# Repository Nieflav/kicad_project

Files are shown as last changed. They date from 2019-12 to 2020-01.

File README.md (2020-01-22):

# Arduino Gas Sensor shield

This PCB was created using KiCad. The schematic has been created from an Arduino Uno shield template. As a consequence, this board will be easily pluggable on top of an Arduino Uno. This board includes a TO-5 package socket for the gas sensor [U4] (supplied by the +3V3 output of the Arduino [pin 4]).

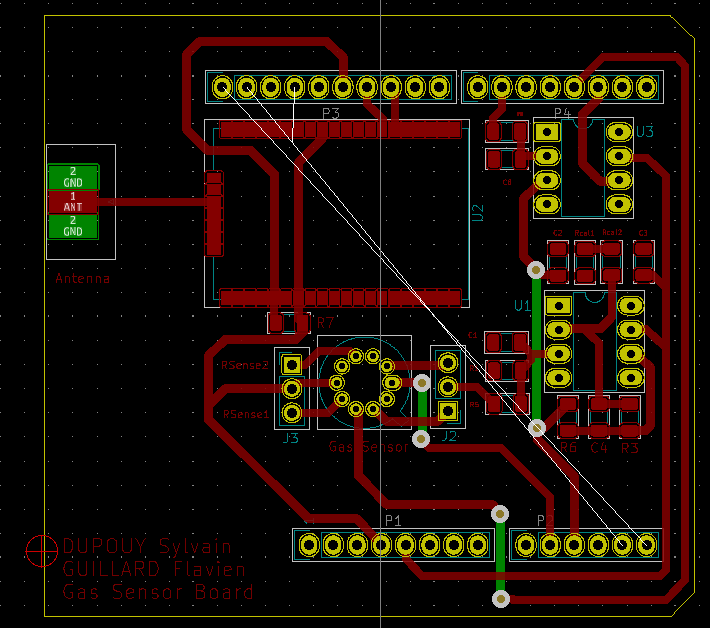
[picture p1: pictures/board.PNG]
Board


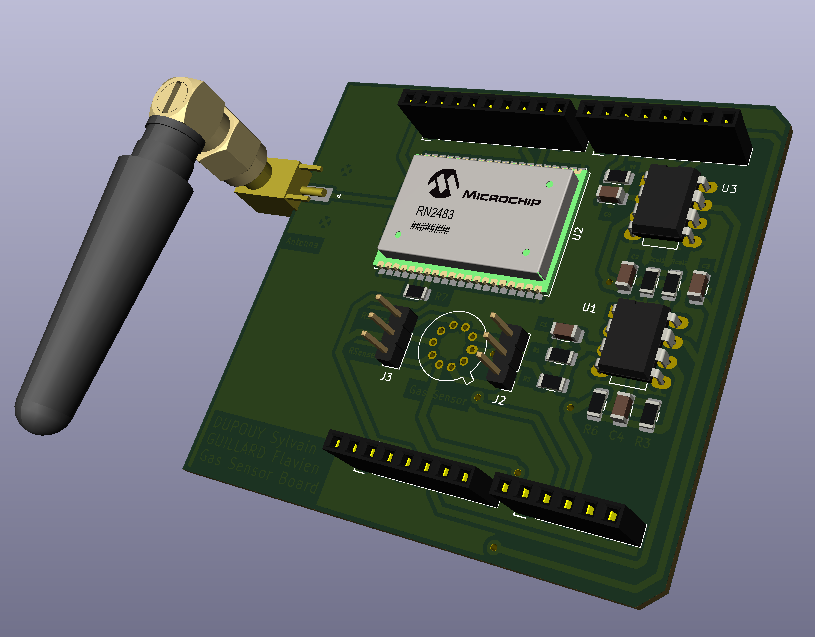
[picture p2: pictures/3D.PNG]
PCB 3D View 3D View


## Sensor operation

A conditioner circuit, based on an operational amplifier [U1] (supplied on the +5V output of the Arduino[pin 5]), is included to amplify and filter the signal before it can be received by the Arduino on a analog input [A2].

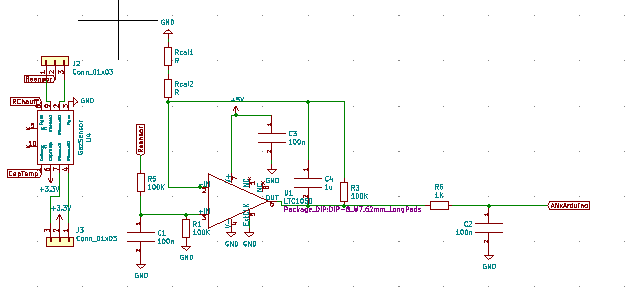
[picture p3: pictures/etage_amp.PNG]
Conditioner stage


Another analog input [A1] is used for temperature monitoring of the gas. The [pin 3] (output) is connected to the  heat resistor of the sensor to control the operating temperature. 

Two jumpers [J2 & J3] are used to choose the gas sensor (between the two available on the package [RSense1 & RSense2]) for the input of the conditioner. They have to be on the same position.

A comparator [U3] (based on an other operational amplifier ) used to detect a anormal value of gas defined by a voltage reference given by the Arduino [pin 6] (PWM). This allows the Arduino to be in sleep mode and to be woken up with an interrupt from the output of the aplifier [pin 2].

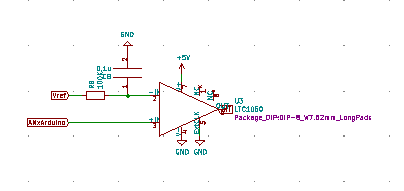
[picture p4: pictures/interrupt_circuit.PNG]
Comparator stage


## LoRA feature

A RN2483 module is included on the shield, ready to be soldered on it. It transmits a LoRA message on TheThingsNetwork platform in case of anormal gas value. It communicates using UART through its [pins 6 & 7] to the [pins 10 & 11] of the Arduino.
The RN2483 module is powered through [pin 12] with the +5V output of the Arduino.

An antenna has to be connected to the [pin 23] to transmit the LoRA messages. It can be installed through a SMA connector [J1].

A gound plane has been added on both faces (top and bottom). Every components can be soldered on the top face (included the gas sensor package and the two operational amplifier which are THT).

All the SMD components are 1206_3216 Metric.

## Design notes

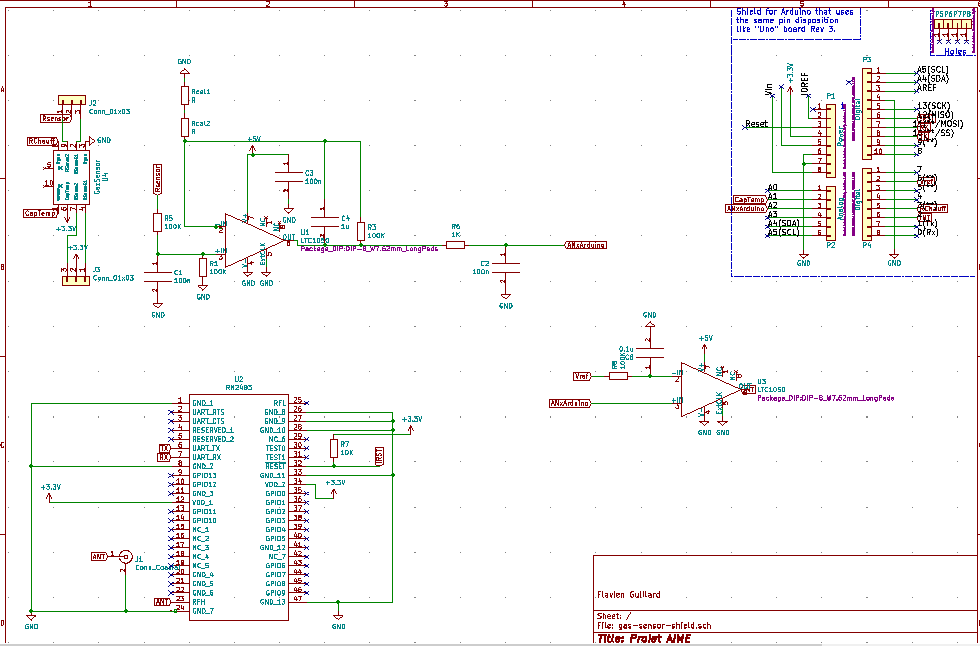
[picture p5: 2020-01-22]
pictures/schematic.PNG

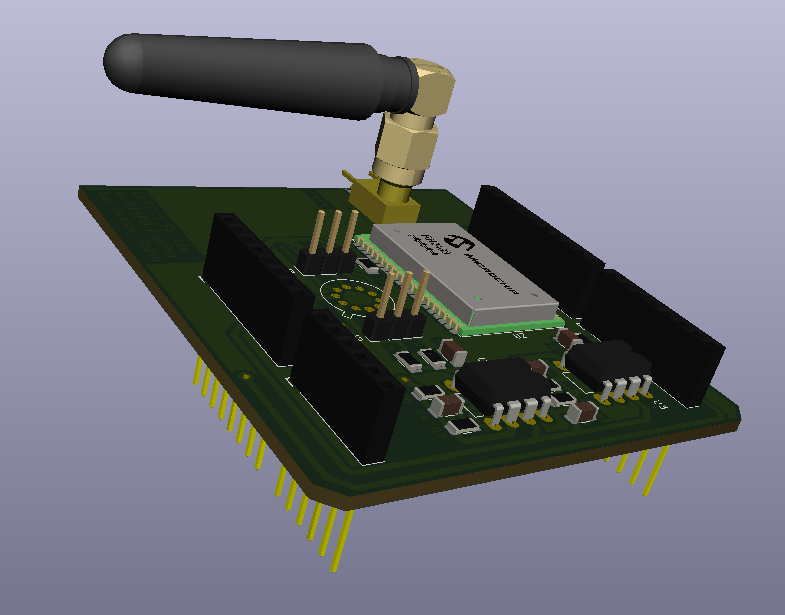
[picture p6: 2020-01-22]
pictures/3D3.PNG

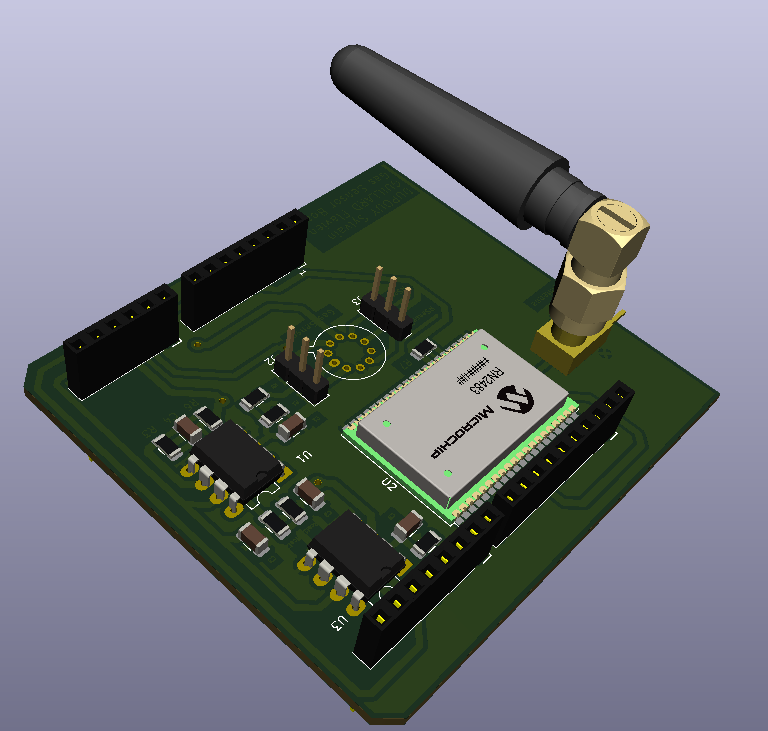
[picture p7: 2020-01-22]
pictures/3D2.PNG

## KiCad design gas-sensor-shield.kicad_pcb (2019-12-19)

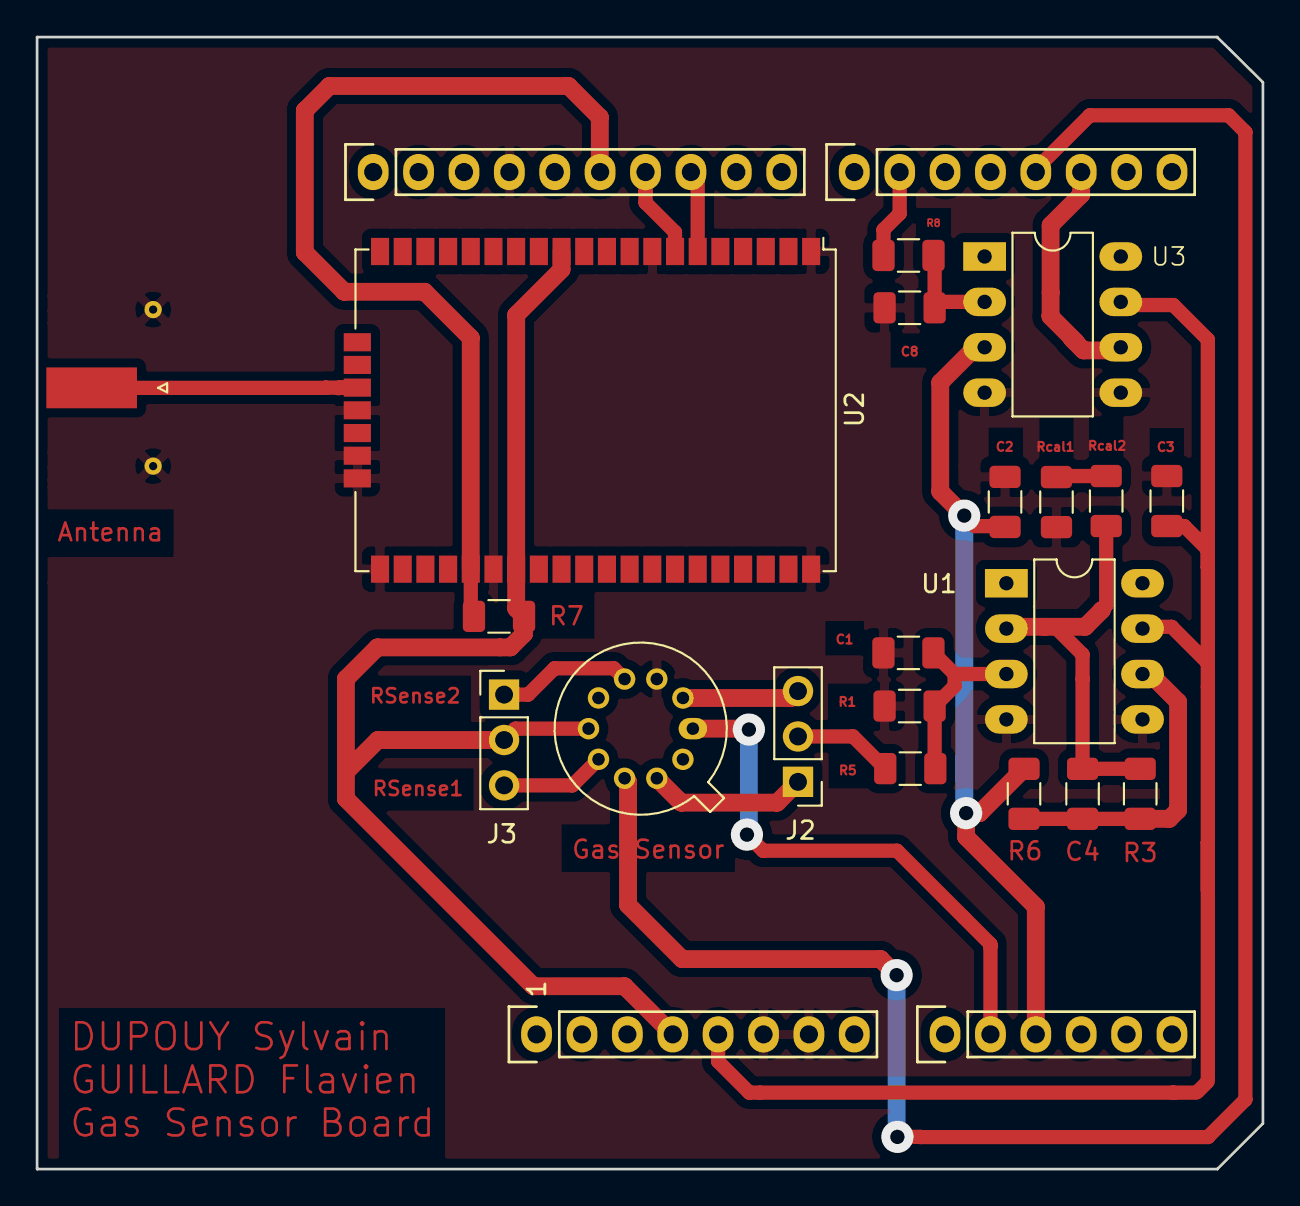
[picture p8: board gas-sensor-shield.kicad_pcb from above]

Board: 2 copper layers, 68.6 x 63.4 mm, 24 parts (0 on the bottom side), 24 nets.

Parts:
Antenna: Conn_Coaxial; SMA_Molex_73251-1153_EdgeMount_Horizontal
C1, C2, C3: 100n; C_1206_3216Metric
C4: 1u; C_1206_3216Metric
C8: 0,1u; C_1206_3216Metric
Gas Sensor: GazSensor; TO-5-10
J2, J3: Conn_01x03; PinHeader_1x03_P2.54mm_Vertical
P1: Power; Socket_Strip_Arduino_1x08
P2: Analog; Socket_Strip_Arduino_1x06
P3: Digital; Socket_Strip_Arduino_1x10
P4: Digital; Socket_Strip_Arduino_1x08
R1, R3, R5, R8: 100K; R_1206_3216Metric
R6: 1K; R_1206_3216Metric
R7: 10K; R_1206_3216Metric
Rcal1, Rcal2: R; R_1206_3216Metric
U1, U3: LTC1050; DIP-8_W7.62mm_LongPads
U2: RN2483

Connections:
!RST: P3.6, R7.2, U2.32
+3V3: Gas Sensor.6, J3.2, P1.4, R7.1, U2.12, U2.34
+5V: C3.1, U1.7, U3.7
/A4(SDA): P2.5, P3.2
/A5(SCL): P2.6, P3.1
ANT: Antenna.1, U2.23
ANxArduino: C2.1, P2.3, R6.1, U3.3
CapTemp: Gas Sensor.1, P2.2
GND: Antenna.2, C1.2, C2.2, C3.2, C8.2, Gas Sensor.3, P1.6, P1.7, P3.4, R1.2, Rcal1.1, U1.4, U1.5, U2.1, U2.8, U2.24, U2.26, U2.27, U2.28, U2.33, U2.47, U3.4, U3.5
INT: P4.6, U3.6
unnamed: C1.1, R1.1, R5.2, U1.3
unnamed: C4.1, R3.1, Rcal2.2, U1.2
unnamed: C4.2, R3.2, R6.2, U1.6
unnamed: C8.1, R8.2, U3.2
unnamed: Gas Sensor.9, J2.1
unnamed: Gas Sensor.2, J2.3
unnamed: Gas Sensor.4, J3.1
unnamed: Gas Sensor.7, J3.3
unnamed: Rcal1.2, Rcal2.1
RChauff: Gas Sensor.8, P4.5
RX: P3.7, U2.7
Rsensor: J2.2, R5.1
TX: P3.8, U2.6
Vref: P4.2, R8.1

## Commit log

2019-11-12 first schematic
    [myproject_uno.kicad_pcb, myproject_uno.sch]
2019-11-12 creation of first pcb kicad
    [myproject_uno.kicad_pcb, myproject_uno.sch]
2019-11-21 pcb almost designed
    [TO-5-4.sch, myproject_uno.kicad_pcb, myproject_uno.sch]
2019-11-21 pcb redesigned and resized, gnd plane missing
    [myproject_uno.kicad_pcb]
2019-11-25 last version of PCB
    [myproject_uno.kicad_pcb, myproject_uno.sch]
2019-12-02 pcb with 8 pins
    [myproject_uno.kicad_pcb, myproject_uno.sch]
2019-12-19 final version
    [TO-5-4.sch, myproject_uno.kicad_pcb, myproject_uno.sch]
2019-12-22 move project root and rename project
    [gas-sensor-shield.kicad_pcb, gas-sensor-shield.sch]
